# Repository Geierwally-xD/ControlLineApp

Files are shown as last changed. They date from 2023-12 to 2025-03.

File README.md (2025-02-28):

# ControlLineApp
Geierwally's stroke engine throttle control application for controlled line model planes
Display-picture
- Realizes full throttle control over control lines
- optional automatic flight position depended throttle control
- flight position sensor = MPU 6050 gyroscope accelerometer unit
- optional functions like retractable landing gear
Display-picture
- Hardware PCB design included, done with KiCad 8.0
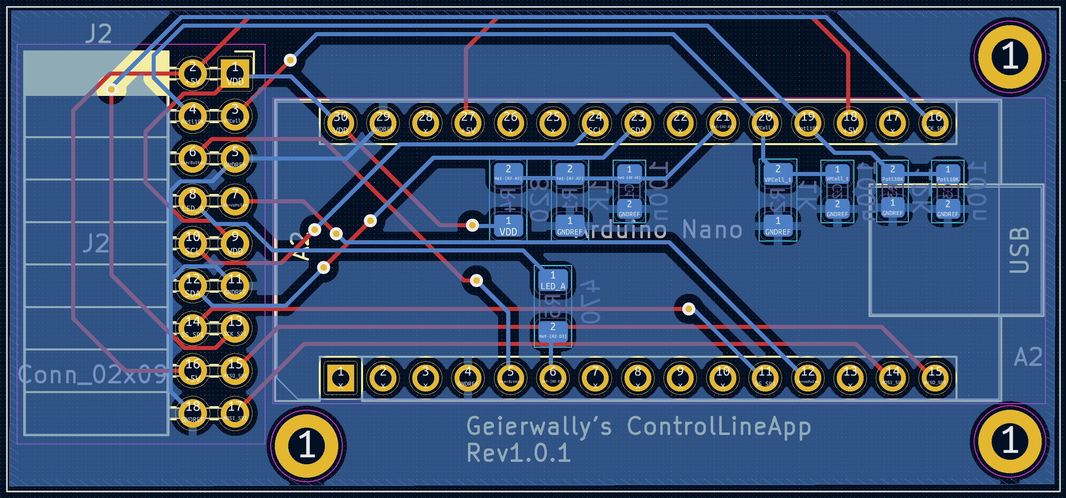
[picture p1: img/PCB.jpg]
Display-picture

- Full Software project included, done for Arduino Nano with VS Code and PlatformIO (optional Arduino IDE)
- See short video clip of position control and landing gear with landing light:
https://www.youtube.com/watch?v=91i4-DDLWDE

Geierwally's Verbrennungsmotor- Drosselvergasersteuerung für Fesselflugmodelle
Display-picture
- Drosselvergaser - Steuerung über Steuerdrähte mit optional automatischer Regelung über Fluglageerkennung
- Fluglagenerkennung über MPU 6050 Gyroskop Accelerometer - Einheit
- Optionale Funktionen wie Einziehfahrwerk
Display-picture
- Komplettes Hardware Platinenlayout enthalten, mit KiCad 8.0 entflochten
Display-picture
- Komplettes Software Projekt enthalten, für  Arduino Nano, entwickelt mit VS Code und PlatformIO (optional Arduino IDE)
- Kurzer Videoclip zeigt Regelung über Fluglage sowie Einziehfahrwerk und Landescheinwerfer:
https://www.youtube.com/watch?v=91i4-DDLWDE

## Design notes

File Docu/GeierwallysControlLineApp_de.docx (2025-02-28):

# Geierwally‘s Control – Line – Application

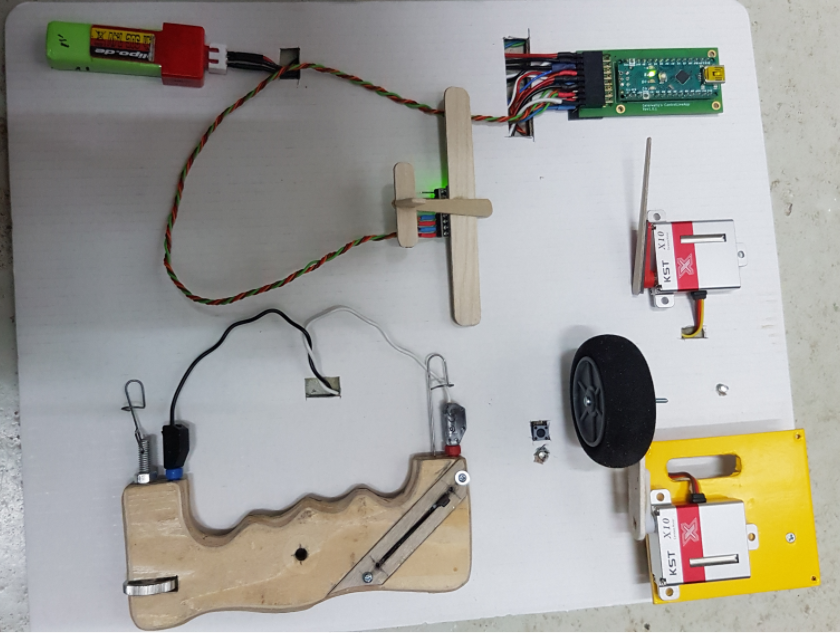
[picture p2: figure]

Geierwally‘s Control – Line – Application (GCLA) realisiert eine Drosselsteuerung in Verbindung mit einer Lagekontrolle und Zusatzfunktionen für Fesselflugmodelle mit Verbrennungsmotor.

Diese ermöglicht den Start des Modells ohne Helfer, einen jederzeit unterbrechbaren Flug sowie eine optionale fluglagenabhängige automatische Steuerung des Drosselvergasers.

Das Geberpoti für die Gassteuerung befindet sich im Steuergriff. Das Gebersignal wird durch die beiden Steuerlitzen übertragen, von einem Mikrocontroller (Arduino Nano) ausgewertet und über ein Servo mechanisch an den Drosselvergaser des Antriebsmotors weitergeleitet. Eine LED im Randbogen des Modells signalisiert den Betriebszustand des Controllers, sowie während des Fluges die verbleibende Flugzeit. Optional kann während des Fluges die lageabhängige Drosselsteuerung aktiviert bzw. deaktiviert werden. Die Lagesteuerung stellt den Motor automatisch im Steigflug mager bzw. im Sinkflug fetter. Die Regelbereiche sind teachbar. Optional kann Expo von 10 – 100% auf die Regelung gemappt werden. Ebenso sind minimale Drosselposition sowie die Position für Motorabsteller teachbar. Flugzeiten sind von 1 – 10 Minuten einstellbar. Nach jeder Minute wird die verbleibende Flugzeit über die Status-LED blinkend angezeigt. Ist die Flugzeit abgelaufen, wird dies durch Dauerblinken der LED sowie durch kurzes Drosseln des Motors für eine Sekunde signalisiert.

Zusätzlich werden vom Mikrocontroller noch beide Zellspannungen des Versorgungsakkus (2S LiPo 330 mAh) überwacht. Sinkt diese bei einer oder beiden Zellen unter 3,5 V, wird dies ebenso durch Dauerblinken der Status – LED signalisiert. Über kurze Drosselimpulse können die Fluglageregelung ein- bzw. ausgeschaltet sowie Zusatzfunktionen wie Einziehfahrwerk oder Landescheinwerfer gesteuert werden.

## 1. Beschreibung der Hardwarekomponenten

Kern der Steuerung ist ein Arduino Nano Mikrocontroller. Sensor für die Fluglageregelung ist eine MPU 6050 Gyroskop- Accelerometer – Einheit. Einlesen der Sensorsignale erfolgt über I²C Schnittstelle. Weitere Anschlussbelegungen sind anhand des Schaltplanes und Layouts im KiCad Projekt ersichtlich. Als Geber für die Gassteuerung dient ein lineares Potentiometer, welches im Steuergriff des Fesselflugmodells verbaut ist.

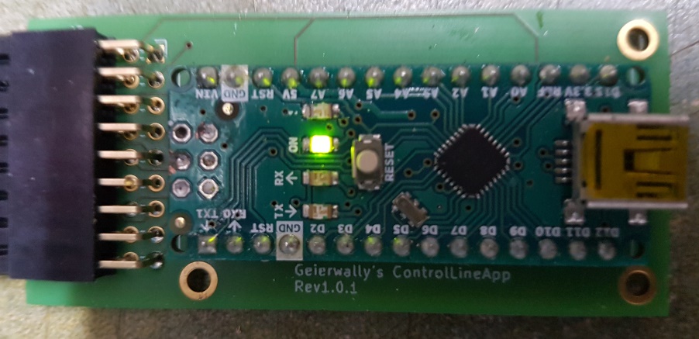
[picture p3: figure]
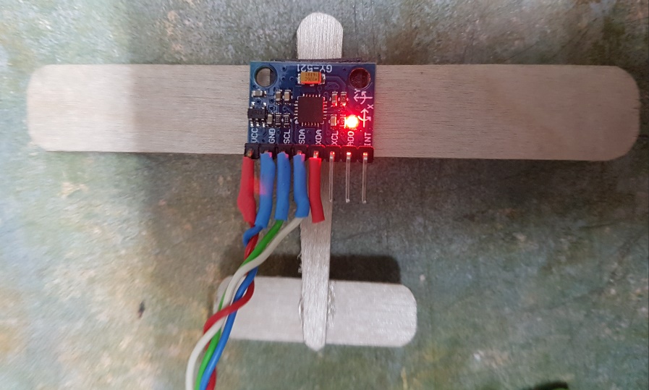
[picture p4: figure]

## 2. Einbau der Steuerkomponenten ins Modell

Controllerplatine, Versorgungsakku sowie das Servo können je nach Platz in Tragfläche oder Rumpf eingebaut werden. Hierbei sollte der Akkuschacht leicht zugänglich sein. Die MPU 6050 Gyroskop – Einheit sollte am Drehpunkt der Quer und Längsachse eingebaut werden. Hierbei kann man die MPU 6050 Sensoreinheit optional normal oder invertiert nach unten hängend montieren. Die Sensoreinheit unbedingt schwingungsgedämpft am besten mittels Klebepads für Helikreisel montieren!

Das Gebersignal vom Steuergriff wird über Mikro- Bananenbuchsen in den inneren Randbogen der Tragfläche verbunden. Zur Vermeidung des Kurzschlusses der Geberleitung ist das Steuerdreieck des Fesselflugmodells aus nichtleitendem Material wie z.B. Pertinax anzufertigen.

## 3. Stromlaufplan

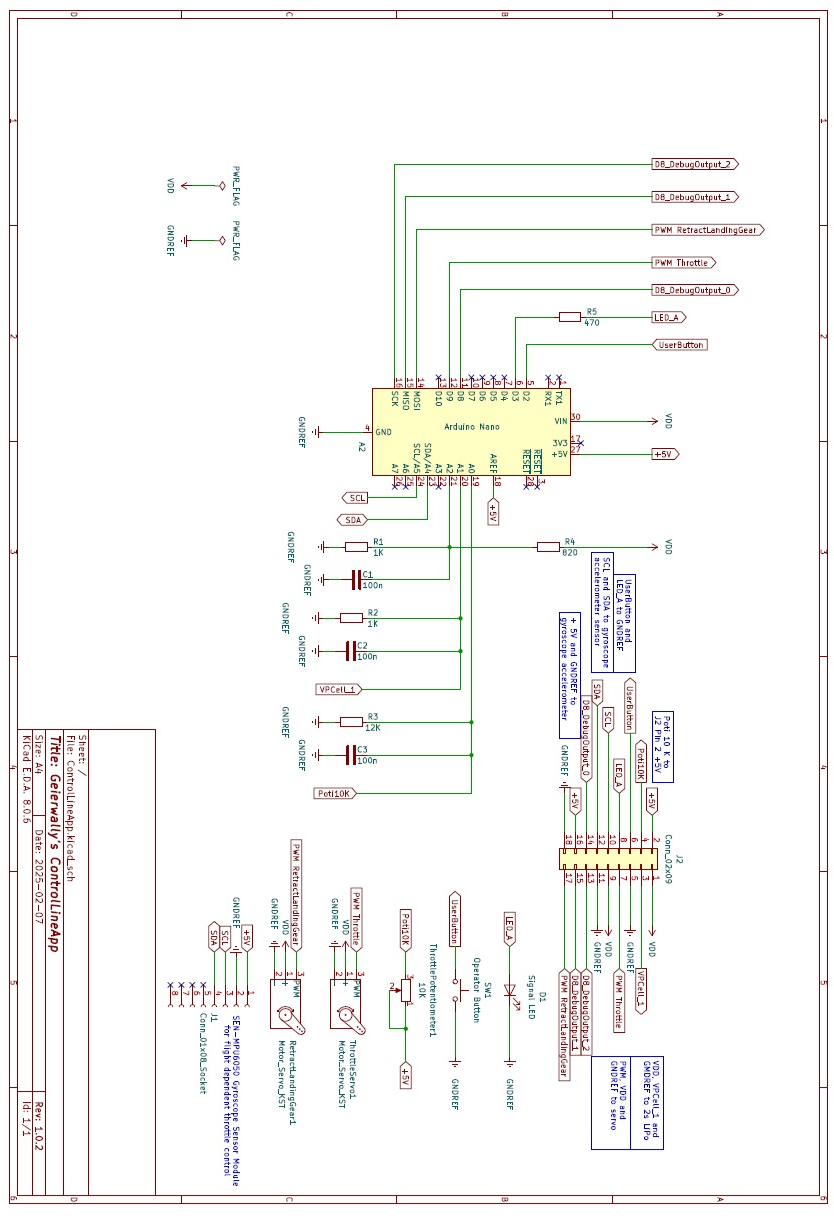
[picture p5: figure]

## 4. Anlernen von Servopositionen , Flugzeittimer und Spannungsüberwachung

Zur Vermeidung mechanischer Blockaden sind vorm ersten Teach der Servopositionen die Steuergestänge vom Servo zum Drosselvergaser sowie wenn verwendet zum Einziehfahrwerk zu lösen.

Die vordere Endlage des Servos (Vollgas) ist mechanisch blockadefrei einzustellen. Gleiches gilt für Einziehfahrwerk eingefahren.

Um ins Teachmenü zu kommen, ist der Anwenderbutton gedrückt zu halten, bis die Status LED das entsprechende Menü durch Blinken signalisiert. Folgende Hauptteachmenüpunkte sind implementiert:

Teach Servo Drosselposition 2 * blinken

Teach Servo Endlage (Motor Absteller) 3 * blinken

Teach Servo revers 4 * blinken

Geberpoti Endlagen 5 * blinken

Einziehfahrwerk 6* blinken

Spannungsüberwachung 7 * blinken

Gyroskop – Teachmenü 8 * blinken

Flugzeit – Timer 9 * blinken

Der Positionsteach wird in den folgenden Schritten beschrieben und sollte genau in dieser Reihenfolge durchgeführt werden.

### 4.1. Anlernen der Geberendlagen (Hauptmenü 5 * blinken)

Hierzu den Menübutton so lange gedrückt halten, bis die Status LED in Folge fünf Mal geblinkt hat.

Im Untermenü blinkt die LED einmal bzw. zweimal je Endlage. Das Poti zunächst in eine Endlage stellen und den Teachbutton kurz betätigen. LED blinkt jetzt zweimal, damit das Poti in die zweite Endlage bringen und mit kurzem Button-Klick bestätigen. Die Positionen sind jetzt permanent im E²Prom des Mikrocontrollers gespeichert.

### 4.2. Servo Stellrichtungsumkehr, nur wenn erforderlich (Hauptmenü 4 * blinken)

Hierzu den Menübutton solange gedrückt halten, bis die Status LED in Folge vier Mal geblinkt hat. Dieser Menüpunkt ist nur zu wählen, wenn das Servo je nach Einbaulage im Modell Stellrichtungsumkehr benötigt. In diesem Menüpunkt ist keine Bestätigung mittels Teachbutton erforderlich. Das Servo aktiviert bzw. deaktiviert die Stellrichtungsumkehr. Auch diese Position ist damit permanent im E²Prom des Mikrocontrollers gespeichert.

### 3.3 Servo Endlage Motorabsteller (Hauptmenü 3 * blinken)

Geber in Mittelposition bringen und den Menübutton solange gedrückt halten, bis die Status LED in Folge drei Mal geblinkt hat. Geber in Position stellen, dass Drosselvergaser in Endlage für Motorabsteller steht, ohne zu blockieren. Die Position mit kurzer Betätigung des Menübuttons bestätigen. Die Position bleibt im E²Prom des Mikrocontrollers gespeichert.

### 3.4 Servo Minimale Drosselposition (Hauptmenü 2 * blinken)

Geber in Mittelposition bringen und den Menübutton solange gedrückt halten, bis die Status LED in Folge zwei Mal geblinkt hat. Geber in Position stellen, dass Drosselvergaser in minimaler Drosselposition steht. Diese Position sollte zuvor mit laufendem Motor getestet und am Geberstick markiert werden. Gleiches gilt für alle weiteren Drosselvergaserpositionen. Position mit kurzer Betätigung des Menübuttons bestätigen. Die Position bleibt im E²Prom des Mikrocontrollers gespeichert.

### 3.5 Versorgungsspannung Einzelzellüberwachung (Hauptmenü 7 * blinken)

Mit dieser Funktion werden die beiden Analog- / Digitalwandler Eingänge der Spannungsüberwachung kalibriert. Dazu den Versorgungsakku komplett aufladen, bis Einzelzellspannung von 4,2 Volt erreicht ist. Den Akku anstecken, Menübutton solange gedrückt halten, bis die Status-LED sieben Mal in Folge blinkt. Eine weitere Bestätigung ist in dieser Teachfunktion nicht notwendig. Der Kalibrierwert wird im E²Prom des Mikrocontrollers permanent gespeichert. Fällt nun eine oder beide LiPo- Zellen unter 3,5 Volt, signalisiert die Status- LED den Fehler mit Dauerblinken.

### 3.6 Einstellung Flugzeittimer (Hauptmenü 9 * blinken)

Mit dieser Funktion wird der Flugzeittimer eingestellt. Zeiten von 1 Minute – 10 Minuten sind je nach Tankgröße und daraus resultierender Motorlaufzeit möglich. Ist der Timer aktiv, werden während des Fluges jede Minute durch Blinken der Status-LED die verbleibende Flugzeit in Minuten signalisiert. Ist Ende der Flugzeit erreicht, geht die Status-LED ins Dauerblinken über und der Motor drosselt kurz für eine Sekunde. Ende Flugzeit sollte natürlich signalisieren, bevor der Tank leer ist, damit man mit der Drosselfunktion noch sicher landen kann.

Zum Teach den Menübutton solange gedrückt halten, bis die Status-LED in Folge neun Mal blinkt.

Man befindet sich nun im Submenü und die LED blinkt ein bis zehn Mal je Anzahl der Flugminuten. Man muss hier bei der gewünschten Minutenzahl mit dem Menübutton kurz bestätigen. Auch diese Daten bleiben permanent gespeichert. Der Flugzeittimer wird durch kurzes Betätigen des Menübuttons gestartet und ebenso wieder gestoppt. Flugzeitende bestätigt man auch durch kurzes Betätigen des Menübuttons. Ist der Timer gestartet, signalisiert er sofort mit LED blinken die eingestellte Flugzeit.

## 5. Fluglageabhängige Drosselsteuerung über Gyroskop Accelerometer (Hauptmenü 8 * blinken)

Die GCLA verfügt über eine optional aktivierbare fluglageabhängige Drosselsteuerung. Die Erfassung der Fluglage erfolgt über eine MPU 6050 Gyroskop – Accelerometer- Sensoreinheit. Zur Lageregelung werden die Drosselpositionen für Neutral und Rückenflug (70 – 80% Drehzahl) sowie die Drosselposition für Sturzflug (zwischen 5 – 20% Drehzahl) geteacht. Die Drehzahlpositionen sollten vorm Teach bei laufendem Motor mit Drehzahlmesser eingestellt und am Geber markiert werden. Das erleichtert den späteren Teach.

Die Fluglageregelung kann während des Fluges jederzeit mit kurzem Drosseln des Motors ein – bzw. ausgeschaltet werden. Dies wird über die Status LED signalisiert. Zwei Mal kurz blinken = Lageregelung ein. Das optionale Deaktivieren ermöglicht einen Start des Modells ohne Lageregelung und mit Vollgas. Sonst wären ja in Neutrallage nur die angelernten 70 – 80% Drehzahl aktiv. Fürs Starten sollte es schon Vollgas sein. In Folge die Beschreibung des Lageregelungs- Teach- Submenüs

Um ins Lageregelungs Teach- Submenü zu kommen, den Menübutton solange gedrückt halten, bis die Status-LED acht Mal in Folge blinkt. Man befindet sich nun im Submenü der Lageregelung.

Folgende Submenüpunkte sind implementiert:

Sensoreinheit normale Einbaulage 1 * blinken

Sensoreinheit hängende Einbaulage 2 * blinken

Sensoreinheit kalibrieren 3 * blinken

Drosselposition Normalflug 4 * blinken

Drosselposition Sturzflug 5 * blinken

Expo 6 * blinken

Lageregelung ein / aus 7 * blinken

Servo Empfindlichkeit 8 * blinken

Lageregelung Teachmenü verlassen 9 * blinken

### 4.1 Normale Einbaulage Gyroskop- Accelerometereinheit (Submenü 1 * blinken)

Diese Option wählen, wenn die Gyroskop- Accelerometer – Sensoreinheit normal von oben montiert ist. Je nach Platz im Modell, kann diese von oben normal oder von unten hängend montiert werden. Die Sensoreinheit sollte am Drehpunkt der Quer und Längsachse schwingungsgedämpft montiert werden. Hierzu können Klebepads von Helikreiseln verwendet werden. Für diese Funktion nach einmaligem LED blinken mit dem Menübutton kurz bestätigen. Die Option wird gespeichert und man befindet sich sofort wieder im Gyro - Teach – Submenü.

### 4.2 Hängende Einbaulage Gyroskop- Accelerometereinheit (Submenü 2 * blinken)

Diese Option wählen, wenn die Gyroskop- Accelerometer – Sensoreinheit hängend montiert wurde. Funktion ist sonst analog zu Menüpunkt 4.1. Den Teach nach zweimaligem blinken der Status – LED mit dem Menübutton bestätigen.

### 4.3 Kalibrierung der Gyroskop- Accelerometereinheit (Submenü 3 * blinken)

Mit diesem Menüpunkt wird die Gyroskop- Accelerometereinheit kalibriert. Dazu nach dreimaligem LED- Blinken mittels Menübuttonklick bestätigen. Die Kalibrierung dauert eine Minute. In dieser Zeit sollte das Modell in allen Achsen gedreht werden, dass der Sensor in alle möglichen Fluglagen kommt. Nach einer Minute werden die ermittelten Kalibrierdaten permanent gespeichert und man ist automatisch wieder im Gyro – Teach - Submenü.

### 4.4 Lagekontrolle Normalflug - Drosselposition (Submenü 4 * blinken)

Hiermit wird die Drosselposition für Normalflug / Rückenflug geteacht. Diese sollte zwischen 70 und 80% Drehzahl liegen. Am besten vorher mit Drehzahlmesser ermitteln und am Geber markieren. Zum Teach der Position im Submenü nach viermaligem LED blinken mit Menübutton bestätigen, den Geber in die gewünschte Position bringen und mit nochmaliger kurzer Betätigung des Teachbuttons speichern. Danach ist man wieder im Gyro – Teach - Submenü.

### 4.5 Lagekontrolle Sturzflug - Drosselposition (Submenü 5 * blinken)

Hiermit wird die Drosselposition für Sturzflug geteacht. Diese sollte zwischen 5 und 15% Drehzahl liegen. Am besten vorher mit Drehzahlmesser ermitteln und am Geber markieren. Zum Teach der Position im Submenü nach fünfmaligem LED blinken mit Menübutton bestätigen, den Geber in die gewünschte Position bringen und mit nochmaliger kurzer Betätigung des Teachbuttons speichern. Danach ist man wieder im Gyro – Teach - Submenü.

### 4.6 Expo Lagekontrolle (Submenü 6 * blinken)

Mit dieser Funktion kann man die fluglagenabhängige Drosselsteuerung mit Expo überlagern. Dies funktioniert auf ähnliche Weise wie man Expo bei den RC Modellen verwendet. Zur Funktionswahl im Submenü nach sechsmaligem LED blinken mit Menübutton bestätigen.

Man kann nun zwischen 0% = lineare Regelkurve und 100% = maximale exponentielle Überlagerung in Zehnerschritten wählen. Folgende Regelkurven wurde direkt mit der Steuerung aufgezeichnet und verdeutlichen die Anwendung von Expo auf die Drosselsteuerung:

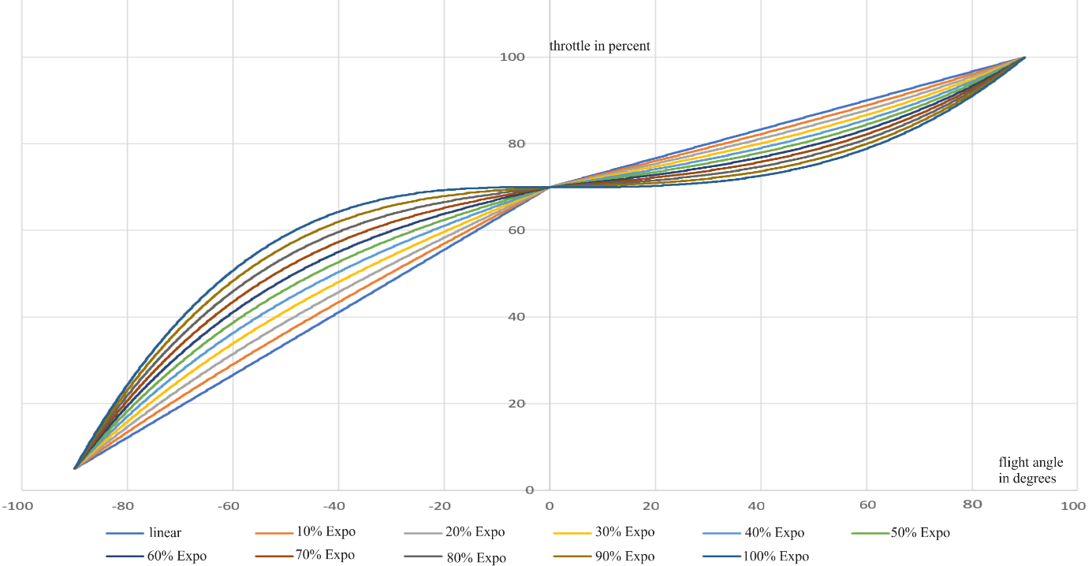
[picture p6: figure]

X- Achse zeigt Flugwinkel von -90° = senkrechter Sturzflug, 0° = Neutralfluglage, 90° = senkrechter Steigflug

Y- Achse zeigt Drosselstellung (0 - 100 Prozent von maximaler Drehzahl)

Zum Expo - Teach im Submenü nach sechsmaligem LED blinken mit Menübutton bestätigen.

Im Expo – Teach – Menü blinkt die Status – LED von ein bis zehnmal kurz zur Wahl der Expo in Prozent. Einmal blinken = 10% Expo, zweimal blinken = 20% Expo…..zehnmal blinken = 100% Expo. Nach dem Blinken der gewünschten prozentualen Expo mit Menübutton kurz bestätigen. Für lineare Kurve, also keine Expo blinkt die Status LED nach der maximalen Expo - Position einmal lang.

Ob und wieviel Expo benötigt wird, muss man erfliegen. Auch diese Daten bleiben permanent gespeichert.

### 4.7 Fluglageregelung ein / aus (Submenü 7 * blinken)

Diese Option aktiviert (1 * blinken) bzw. deaktiviert (2 * blinken) die Fluglageregelung. Die Lageregelung kann bei aktiviertem Betrieb dann wahlweise mit kurzem Drosseln des Motors während des Fluges ein bzw. ausschalten. Regeln tut es erst, wenn der Drosselgeber auf dem eingestellten Wert für Neutralflug bzw. darüber in Richtung Vollgas steht. Man kann also auch bei aktiver Fluglageregelung jederzeit den Motor drosseln und den Flug beenden. Die Wirkung der Fluglageregelung wird in folgendem kurzen Videoclip mit maximaler also 100% überlagerter Expo gezeigt. Video GCLA Lageregelung (https://www.youtube.com/shorts/paRSoQgenMU)

Zur Funktionswahl im Submenü nach ein- bzw. zweimaligem LED blinken mittels Menübutton bestätigen. Damit wird die Option permanent gespeichert und man ist wieder im Gyro – Teach – Submenü.

### 4.8 Fluglageregelung Servoempfindlichkeit (Submenü 8 * blinken)

Diese Option startet den Teach der Servoempfindlichkeit. Zwischen einmaligem (schnell) bis fünfmaligem (langsam) LED blinken kann man wählen, wie schnell das Servo auf die Lageregelung reagiert. Bei sechsmaligem LED blinken ist die Verzögerung deaktiviert und das Servo reagiert direkt mit maximaler Stellgeschwindigkeit auf die Lageregelung. Mittels Bestätigung durch Menübutton wird die Option permanent gespeichert und man ist wieder im Gyro-Teach-Submenü.

### 4.9 Fluglageregelung Teach Submenü beenden (Submenü 9 * blinken)

Mit dieser Option verlässt man das Gyro – Teach – Submenü und ist wieder im normalen Steuermenü. Zur Funktionswahl im Submenü nach neunmaligem LED blinken mit Menübutton bestätigen.

## 6. Einziehfahrwerk und Zusatzfunktionen (Hauptmenü 6 * blinken)

In der GCLA sind drei digitale Zusatzfunktionen sowie die Steuerung eines Einziehfahrwerks realisiert. Diese können im Flugbetrieb mittels kurzer Drosselimpulse geschaltet werden. Zwei kurze Drosselimpulse steuern das Einziehfahrwerk. Drei, vier und fünf kurze Drosselimpulse schalten die digitalen Zusatzfunktionen. Zusatzfunktion 1 kann optional mit dem Einziehfahrwerk verknüpft werden zur Steuerung eines Landescheinwerfers. In dieser Option schaltet die Funktion bei ausgefahrenem Fahrwerk automatisch ein und bei eingefahrenem Fahrwerk automatisch aus. Die folgenden Unterkapitel beschreiben das Teachmenü für die Funktion Einziehfahrwerk.

### 5.1 Servoendlage Einziehfahrwerk ausgefahren (Submenü 1 * blinken)

Mit diesem Menüpunkt wird die Servoendlage des Einziehfahrwerks im ausgefahrenen Zustand angelernt. Die Position wird mit dem Drosselgeber Poti gestellt. Durch Bestätigung mittels Menübutton wird die Position permanent gespeichert. Die Position für eingefahrenes Fahrwerk ist bei maximalem Ausschlag des Servos mechanisch einzustellen.

### 5.2 Einziehfahrwerk Servo Revers (Submenü 2 * blinken)

Diese Option invertiert die Stellrichtung des Einziehfahrwerkservos. Einmaliges LED blinken = normal, zweimaliges LED blinken = invertierte Stellrichtung. Mittels Menübutton wird die Option permanent gespeichert und das Teachmenü des Einziehfahrwerksservos ist aktiv.

### 5.3 Einziehfahrwerk Servo Stellgeschwindigkeit (Submenü 3 * blinken)

Mit diesem Submenü wird die Stellgeschwindigkeit des Einziehfahrwerksservos verändert. Es stehen Optionen von einfach blinken (schnell) bis fünffach blinken (langsam) zur Verfügung. Mit sechsfach blinken wird die maximale Stellgeschwindigkeit aktiviert. Auch hier wird die gewählte Option nach blinken mittels Menübutton permanent gespeichert und ins Teachmenü des Einziehfahrwerksservos zurückgeschaltet.

### 5.4 Verknüpfung Zusatzfunktion Landescheinwerfer (Submenü 4 * blinken)

Dieses Submenü verknüpft optional die digitale Zusatzfunktion 1 mit dem Einziehfahrwerk. Dies kann beispielsweise zum Schalten eines Landescheinwerfers verwendet werden. Folgende Optionen stehen zur Verfügung: einfach blinken = Zusatzfunktion 1 verknüpft (Fahrwerk ausgefahren und Landescheinwerfer ein), zweifach blinken = Zusatzfunktion 1 invertiert verknüpft (Fahrwerk ausgefahren und Landescheinwerfer aus), dreifach blinken = keine Verknüpfung von Zusatzfunktion 1 Mit dem Menübutton wird die Option permanent gespeichert und zurück ins Teachmenü des Einziehfahrwerksservos geschaltet. Auch wenn die Verknüpfung aktiv ist kann die Zusatzfunktion 1 parallel mit drei Drosselimpulsen geschaltet werden.

### 5.5 Teachmenü Einziehfahrwerk beenden (Submenü 5 * blinken)

Mit Bestätigung dieser Option über Menübutton wird das Teachmenü des Einziehfahrwerksservos beendet.

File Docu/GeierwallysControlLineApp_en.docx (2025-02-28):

# Geierwally's Control – Line – Application


Geierwally's Control – Line – Application (GCLA) realizes a throttle control in combination with position control and additional functions for control line models with stroke engines.

This allows the model to be started without helpers, a flight that can be interrupted at any time and an optional automatic control of the throttle carburettor depending on the flight position.

The linear potentiometer for the throttle control is located in the control handle. The encoder signal is transmitted through the two control lines, evaluated by a microcontroller (Arduino Nano) and mechanically transmitted via a servo to the throttle carburettor of the stroke engine. An LED in the edge arc of the model indicates the operating status of the controller, as well as the remaining flight time during the flight. Optionally, the position-dependent throttle control can be activated or deactivated during the flight. The position control automatically makes the engine leaner during ascending - and fatter during descending flight. The control areas can be taught. Optionally, expo from 10 – 100% can be mapped to the control. The minimum throttle position as well as the position for engine shut-off can be also taught. Flight times can be set from 1 – 10 minutes. After each minute, the remaining flight time is flashed by the status LED. If the flight time has elapsed, this is signalled by continuous flashing of the LED and by briefly throttling the engine for one second.

In addition, the microcontroller monitors both cell voltages of the supply battery (2S LiPo 330 mAh). If this drops below 3.5 V for one or both cells, this is also signalled by continuous flashing of the status LED. Short throttle pulses can be used to switch the flight attitude control on or off and to control additional functions such as retractable landing gear or landing lights.

## 1. Description of Hardware Components

The core of the control system is an Arduino Nano microcontroller. The position control sensor is an MPU 6050 gyroscope accelerometer unit. The sensor signals are read in via I²C interface. Further connection assignments can be seen in the circuit diagram and layout in the KiCad project. The encoder for the throttle control is a linear potentiometer, which is installed in the control handle of the control line model.


## 2. Installation of the control components in the model

The controller board, power supply battery and servo can be installed in the wing or fuselage, depending on the space. The battery bay should be easily accessible. The MPU 6050 gyroscope unit should be installed at the pivot point of the transverse and longitudinal axis. The MPU 6050 sensor unit can optionally be mounted normally or inverted and suspended downwards. Be sure to mount the sensor unit vibration-damped, preferably using adhesive pads for helicopter gyroscopes!

The encoder signal from the control handle is connected to the inner edge arch of the wing via micro banana bushings. To avoid a short circuit of the encoder cable, the control triangle of control line model must be made of non-conductive material such as Pertinax.

## 3. Schematic


## 4. Teach-in servo positions, time-of-flight timer and voltage monitoring

To avoid mechanical blockages, the control linkages from the servo to the throttle carburetor and, if used, to the retractable landing gear must be disconnected before the servo positions are taught for the first time. The front end position of the servo (full throttle) can be adjusted mechanically without blockage. The same applies to retractable landing gear retracted. To access the teach menu, press and hold the user button until the status LED signals the corresponding menu by flashing. The following main teach menu items are implemented:

teach servo throttle position 2 * flashing

teach servo end position (motor shut-off) 3 * flashing

teach servo direction 4 * flashing

encoder potentiometer end positions 5 * flashing

retractable landing gear 6 * flashing

voltage monitoring 7 * flashing

gyroscope – teach menu 8 * flashing

flight time – timer 9 * flashing

Position teaching is described in the following steps and should be done exactly in this order.

### 4.1. Teach-in of the encoder end positions (main menu 5 * flashing)

To do this, hold down the menu button until the status LED has flashed five times in a row.

In the submenu, the LED flashes once or twice for each end position. First, place the potentiometer in an end position and press the teach button briefly. LED now flashes twice to bring the potentiometer to the second end position and confirm with a short button click. The positions are now permanently stored in the E²Prom of the microcontroller.

### 4.2. Servo direction reversal, only when required (main menu 4 * flashing)

To do this, press and hold the menu button until the status LED has flashed four times in a row. This menu item can only be selected if the servo needs to be reversed depending on the mounting position in the model. In this menu item, no confirmation via the teach button is required. The servo activates or deactivates the reversal of the direction of travel. This position is also permanently stored in the E²Prom of the microcontroller.

### 3.3 Servo end position motor shut-off (main menu 3 * flashing)

Move the sensor to the middle position and hold down the menu button until the status LED has flashed three times in succession. Position the encoder potentiometer so that the throttle carburettor is in the end position for the engine shut-off without blocking. Confirm the position by briefly pressing the menu button. The position remains stored in the E²Prom of the microcontroller.

### 3.4 Servo Minimum throttle position (main menu 2 * flashing)

Move the encoder potentiometer to the middle position and hold down the menu button until the status LED has flashed twice in succession. Position the potentiometer so that the throttle carburettor is in the minimum throttle position. This position should be tested beforehand with the engine running and marked on the transducer stick. The same applies to all other throttle carburettor positions. Confirm the position by briefly pressing the menu button. The position remains stored in the E²Prom of the microcontroller.

### 3.5 Supply Voltage Single Cell Monitoring (Main Menu 7 * Flashing)

This function is used to calibrate the two analogue to digital converters inputs of the voltage monitor. To do this, fully charge the supply battery until a single-cell voltage of 4.2 volts is reached. Plug in the battery, press and hold the menu button until the status LED flashes seven times in a row. Further confirmation is not necessary in this teaching function. The calibration value is permanently stored in the E²Prom of the microcontroller. If one or both LiPo cells fall below 3.5 volts, the status LED signals the fault with continuous flashing.

### 3.6 Setting flight time timer (main menu 9 * flashing)

This function is used to set the flight time timer. Times of 1 minute – 10 minutes are possible depending on the tank volume and the resulting engine runtime. If the timer is active, the remaining flight time in minutes is signalled every minute during the flight by flashing the status LED. When the end of the flight time is reached, the status LED switches to continuous flashing and the engine throttles briefly for a second. End of flight time should of course signal before the tank is empty, so that you can still land safely with the throttle function.

To teach, press and hold the menu button until the status LED flashes nine times in a row.

You are now in the submenu and the LED flashes one to ten times depending on the number of flight minutes. You have to confirm the desired number of minutes with the menu button. This data is also stored permanently. The time-of-flight timer is started and stopped again by briefly pressing the menu button. The end of the flight time can also be confirmed by briefly pressing the menu button. When the timer is started, it immediately signals the set flight time with LED flashing.

## 5. Position-dependent throttle control via gyroscope accelerometer (main menu 8 * flashing)

The GCLA has an optionally activated position-dependent throttle control. The flight position is recorded by an MPU 6050 gyroscope – accelerometer sensor unit. For position control, the throttle positions for neutral and inverted flight (70 – 80% rpm) as well as the throttle position for dive (between 5 – 20% rpm) are taught. The speed positions should be set with a tachometer before teaching while the engine is running and marked on the encoder. This makes it easier to teach it later.

The position control can be switched on or off at any time during the flight by briefly throttling the engine. This is indicated by the status LED. Blink briefly twice = position control active. The optional deactivation allows the model to be started without position control and at full throttle. Otherwise, only the learned 70 – 80% speed would be active in neutral position. It should be full throttle for the start. Below is the description of the position control teach submenu

To access the Position Control Teach submenu, press and hold the menu button until the status LED flashes eight times in a row. You are now in the submenu of the position control.

The following submenu items are implemented:

sensor unit normal mounting position 1 * flashing

sensor unit hanging mounting position 2 * flashing

calibrate sensor unit 3 * flashing

throttle position normal flight 4 * flashing

throttle position dive 5 * flashing

expo 6 * flashing

position control on / off 7 * flashing

servo sensitivity 8 * flashing

position control leave teach menu 9 * Flashing

### 4.1 Normal mounting position gyroscope accelerometer unit (submenu 1 * flashing)

Select this option if the gyroscope accelerometer sensor unit is normally mounted from above. Depending on the space in the model, it can be mounted normally from above or suspended from below. The sensor unit should be mounted at the pivot point of the transverse and longitudinal axis in a vibration-damped manner. For this purpose, adhesive pads of helicopter gyroscopes can be used. For this function, after a single LED flash, briefly confirm with the menu button. The option will be saved and you will immediately be back in the Gyro - Teach - submenu.

### 4.2 Hanging mounting position gyroscope accelerometer unit (submenu 2 * flashing)

Select this option if the gyroscope accelerometer sensor unit is suspended mounted. Function is otherwise analogous to menu item 4.1. Confirm the teach after blinking the status LED with the menu button.

### 4.3 Calibration of the gyroscope accelerometer unit (submenu 3 * flashing)

This menu item is used to calibrate the gyroscope accelerometer unit. To do this, confirm after flashing the LED three times by clicking on the menu button. Calibration takes one minute. During this time, the model should be rotated in all axes so that the sensor comes into all possible flight positions. After one minute, the calibration data is permanently stored and you are automatically back in the Gyro – Teach – submenu.

### 4.4 Position control normal flight - throttle position (submenu 4 * flashing)

This is used to teach the throttle position for normal flight / inverted flight. This should be between 70 and 80% speed. It is best to determine beforehand with a tachometer and mark it on the encoder. To teach the position in the submenu, after flashing four LEDs, confirm with the menu button, move the encoder to the desired position and save it by pressing the teach button again. After that, you are back in the Gyro – Teach – submenu.

### 4.5 Position control dive - throttle position (submenu 5 * flashing)

This is used to teach the throttle position for diving. This should be between 5 and 15% speed. It is best to determine beforehand with a tachometer and mark it on the encoder. To teach the position in the submenu, after flashing the LED five times, confirm with the menu button, move the encoder to the desired position and save it by pressing the teach button again. After that, you are back in the Gyro – Teach – submenu.

### 4.6 Expo position control (submenu 6 * flashing)

With this function, you can overlay the position-dependent throttle control with expo. This works in a similar way to how you use expo on the RC models.

Confirm with the menu button after status LED has flashed six times. You can now choose between 0% = linear control curve and 100% = maximum exponential superposition in steps of ten. The following control curves were recorded directly with the controller and illustrate the application of expo to throttle control:


X-axis shows flight angle of -90° = vertical descent flight, 0° = normal/invert flight, 90° = vertical ascend flight

Y-axis shows throttle position (0 - 100 percent of maximum speed)

In the Expo – Teach menu, the status LED flashes from one to ten times briefly for the selection of the expo in percentage. One flash = 10% Expo, two flashes = 20% Expo.....ten flashes = 100% Expo. After flashing the desired percentage expo, confirm briefly with the menu button. For linear curve, i.e. no expo, the status LED flashes once long after the maximum expo position.

Whether and how much expo is needed has to be flown. This data is also stored permanently.

### 4.7 Flight control on / off (submenu 7 * flashing)

This option activates (1 * flashing) or deactivates (2 * flashing) position control. The position control in active state can be switched on or off by briefly throttling the engine during the flight. It only regulates when the throttle encoder potentiometer is at the set value for neutral flight or above in the direction of full throttle. This means that you can throttle the engine and end the flight at any time, even with active position control. The effect of the position control is shown in the following short video clip with a maximum expo, i.e. 100% superimposed. Video GCLA Position Control (https://www.youtube.com/shorts/paRSoQgenMU)

To select function in the submenu, confirm with menu button if LED has flashed one or two times. This will save the option permanently and you are back in the Gyro – Teach – submenu.

### 4.8 Flight control servo sensitivity (submenu 8 * flashing)

This option starts teaching the servo sensitivity. Between single (fast) to five (slow) LED flashes, you can choose how quickly the servo reacts to the position control. If the LED flashes six times, the delay is deactivated and the servo reacts directly to the position control at maximum speed. By confirming with the menu button, the option is permanently saved and you are back in the gyro teach submenu.

### 4.9 Flight control leave teach submenu (Submenu 9 * Flashing)

With this option you leave the Gyro – Teach – submenu and are back in the normal control menu. To select function in the submenu, confirm with menu button if LED has flashed nine times.

## 6. Retractable landing gear and additional functions (main menu 6 * flashing)

The GCLA has three additional digital functions as well as the control of a retractable landing gear. These can be switched during flight operation by means of short throttle pulses. Two short throttle pulses control the retractable landing gear. Three, four and five short throttle pulses switch the additional digital functions. Additional function 1 can optionally be linked to the retractable landing gear to control a landing light. In this option, the function switches on automatically when the landing gear is extended and automatically switches off when the landing gear is retracted. The following subchapters describe the teach menu for the retractable landing gear function.

### 5.1 Servo end position retractable landing gear extended (submenu 1 * flashing)

This menu item is used to teach the servo end position of the retractable landing gear when extended. The position is set with the throttle sensor potentiometer. By confirming with the menu button, the position is permanently stored. The position for retracted landing gear must be adjusted mechanically at maximum deflection of the servo.

### 5.2 Retractable landing gear servo revers (submenu 2 * flashing)

This option inverts the direction of control of the retractable landing gear servo. Single LED flashing = normal, flashing LED twice = inverted direction. Pressing menu button saves the option permanently and the teach menu of the retractable landing gear is active.

### 5.3 Retractable landing gear servo speed (submenu 3 * flashing)

This submenu changes the actuation speed of the retractable landing gear servo. Options are available from single flash (fast) to five flashes (slow). The maximum positioning speed is activated with six flashes. Here, too, the selected option is permanently saved by pressing the menu button and switched back to the teach menu of the retractable landing gear.

### 5.4 Link additional function landing lights (submenu 4 * flashing)

This submenu optionally links the digital additional function 1 with the retractable landing gear. This can be used, for example, to switch a landing light. The following options are available: single flashing = additional function 1 linked (landing gear extended and landing lights on), double flashing = additional function 1 inverted linked (landing gear extended and landing lights off), triple flashing = no linking of additional function 1 With the menu button, the option is permanently saved and switched back to the teach menu of the retractable landing gear. Even if the link is active, the additional function 1 can be switched in parallel with three throttle pulses.

### 5.5 Leave teachmenu retractable landing gear (submenu 5 * flashing)

With confirmation of this option via the menu button, the teach menu of the retractable landing gear servo is closed.

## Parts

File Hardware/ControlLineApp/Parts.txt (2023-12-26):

Widerstand 1K 1206
https://www.conrad.de/de/p/tru-components-1584217-tc-hp06w2f1001t5e203-dickschicht-widerstand-1-k-smd-1206-0-5-w-1-100-ppm-c-1-st-tape-cut-1584217.html

Widerstand 470 Ohm 1206
https://www.conrad.de/de/p/tru-components-1585631-tc-hp06w2f4700t5e203-dickschicht-widerstand-470-smd-1206-0-5-w-1-100-ppm-c-1-st-tape-cut-1585631.html

Widerstand 820 Ohm 1206
https://www.conrad.de/de/p/tru-components-tc-1206s4j0821t5e203-dickschicht-widerstand-820-smd-1206-0-25-w-5-100-ppm-c-1-st-tape-cut-1585946.html

Widerstand 12K 0805
https://www.conrad.de/de/p/vishay-dcu-0805-1-12k-dcu-0805-dickschicht-widerstand-12-k-smd-0805-0-125-w-1-100-ppm-1-st-tape-cut-428140.html

Kondensator 100 n 0805
https://www.conrad.de/de/p/samsung-smd-keramik-vielschicht-kondensator-bauform-0805-x7r-100-nf-10-50-v-2752828.html

Buchsenleiste
https://www.conrad.de/de/p/econ-connect-buchsenleiste-standard-anzahl-reihen-2-polzahl-je-reihe-9-blw2x9-1-st-1492395.html

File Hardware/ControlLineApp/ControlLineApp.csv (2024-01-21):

ID | Bezeichner | Footprint | Stückzahl | Bezeichnung | Anbieter und Referenz
1 | A2 | Arduino_Nano | 1 | Arduino Nano
2 | J2 | PinSocket_2x09_P2.54mm_Horizontal | 1 | Conn_02x09 | https://www.conrad.de/de/p/econ-connect-buchsenleiste-standard-anzahl-reihen-2-polzahl-je-reihe-9-blw2x9-1-st-1492395.html
3 | R4 | R_1206_3216Metric_Pad1.30x1.75mm_HandSolder | 1 | 820 | https://www.conrad.de/de/p/tru-components-tc-1206s4j0821t5e203-dickschicht-widerstand-820-smd-1206-0-25-w-5-100-ppm-c-1-st-tape-cut-1585946.html
4 | R3 | R_0805_2012Metric_Pad1.20x1.40mm_HandSolder | 1 | 12K | https://www.conrad.de/de/p/vishay-dcu-0805-1-12k-dcu-0805-dickschicht-widerstand-12-k-smd-0805-0-125-w-1-100-ppm-1-st-tape-cut-428140.html
5 | C1,C3,C2 | C_0805_2012Metric_Pad1.18x1.45mm_HandSolder | 3 | 100n | https://www.conrad.de/de/p/samsung-smd-keramik-vielschicht-kondensator-bauform-0805-x7r-100-nf-10-50-v-2752828.html
6 | R2,R1 | R_1206_3216Metric_Pad1.30x1.75mm_HandSolder | 2 | 1K | https://www.conrad.de/de/p/tru-components-1584217-tc-hp06w2f1001t5e203-dickschicht-widerstand-1-k-smd-1206-0-5-w-1-100-ppm-c-1-st-tape-cut-1584217.html
7 | R5 | R_1206_3216Metric_Pad1.30x1.75mm_HandSolder | 1 | 470 | https://www.conrad.de/de/p/tru-components-1585631-tc-hp06w2f4700t5e203-dickschicht-widerstand-470-smd-1206-0-5-w-1-100-ppm-c-1-st-tape-cut-1585631.html
 |  | PinHeader 2*9 forJ2 |  |  | https://www.conrad.de/de/search.html?search=Stiftleiste%202%20*%209
 |  | ServoCable |  |  | https://www.conrad.de/de/p/econ-connect-kl3x014rtswgn25-litze-3-x-0-14-mm-rot-schwarz-gruen-25-m-2861407.html
 |  | JST XH 1*3 header for 2s Lipo |  |  | https://www.conrad.de/de/p/jst-stiftleiste-standard-xh-polzahl-gesamt-3-rastermass-2-50-mm-800184-1-st-741181.html
 |  |  |  |  | https://www.conrad.de/de/p/weller-t0051402999-loetzinn-bleifrei-sn0-6cu0-05ni-21-g-0-30-mm-0-50-mm-0-80-mm-2489829.html

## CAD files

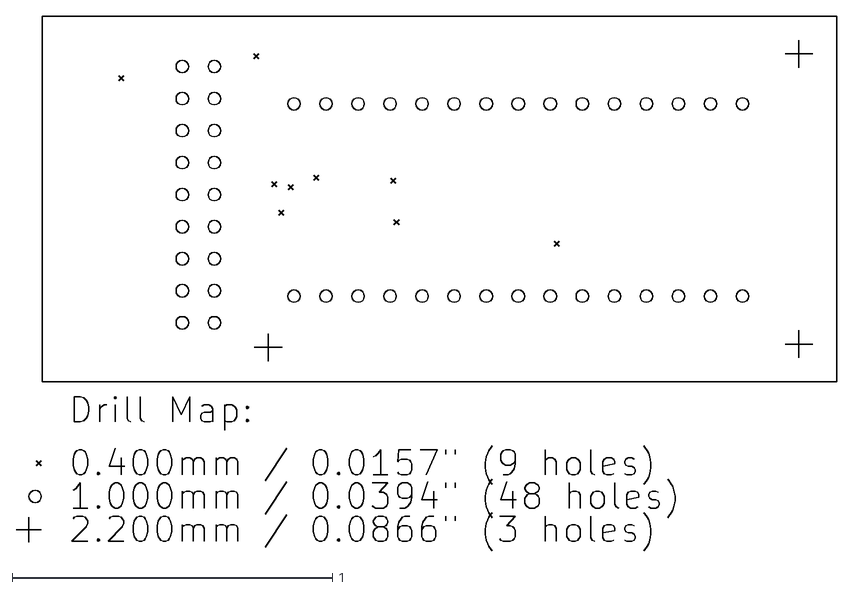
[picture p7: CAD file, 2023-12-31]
Hardware/ControlLineApp/ControlLineApp-PTH-drl_map.dxf
2.56 x 1.67

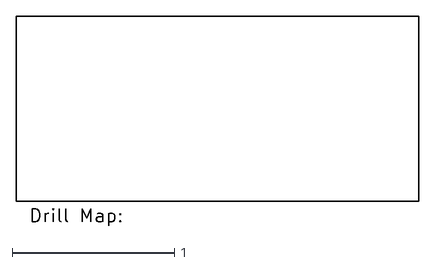
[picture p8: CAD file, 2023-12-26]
Hardware/ControlLineApp/ControlLineApp-NPTH-drl_map.dxf
2.48 x 1.29

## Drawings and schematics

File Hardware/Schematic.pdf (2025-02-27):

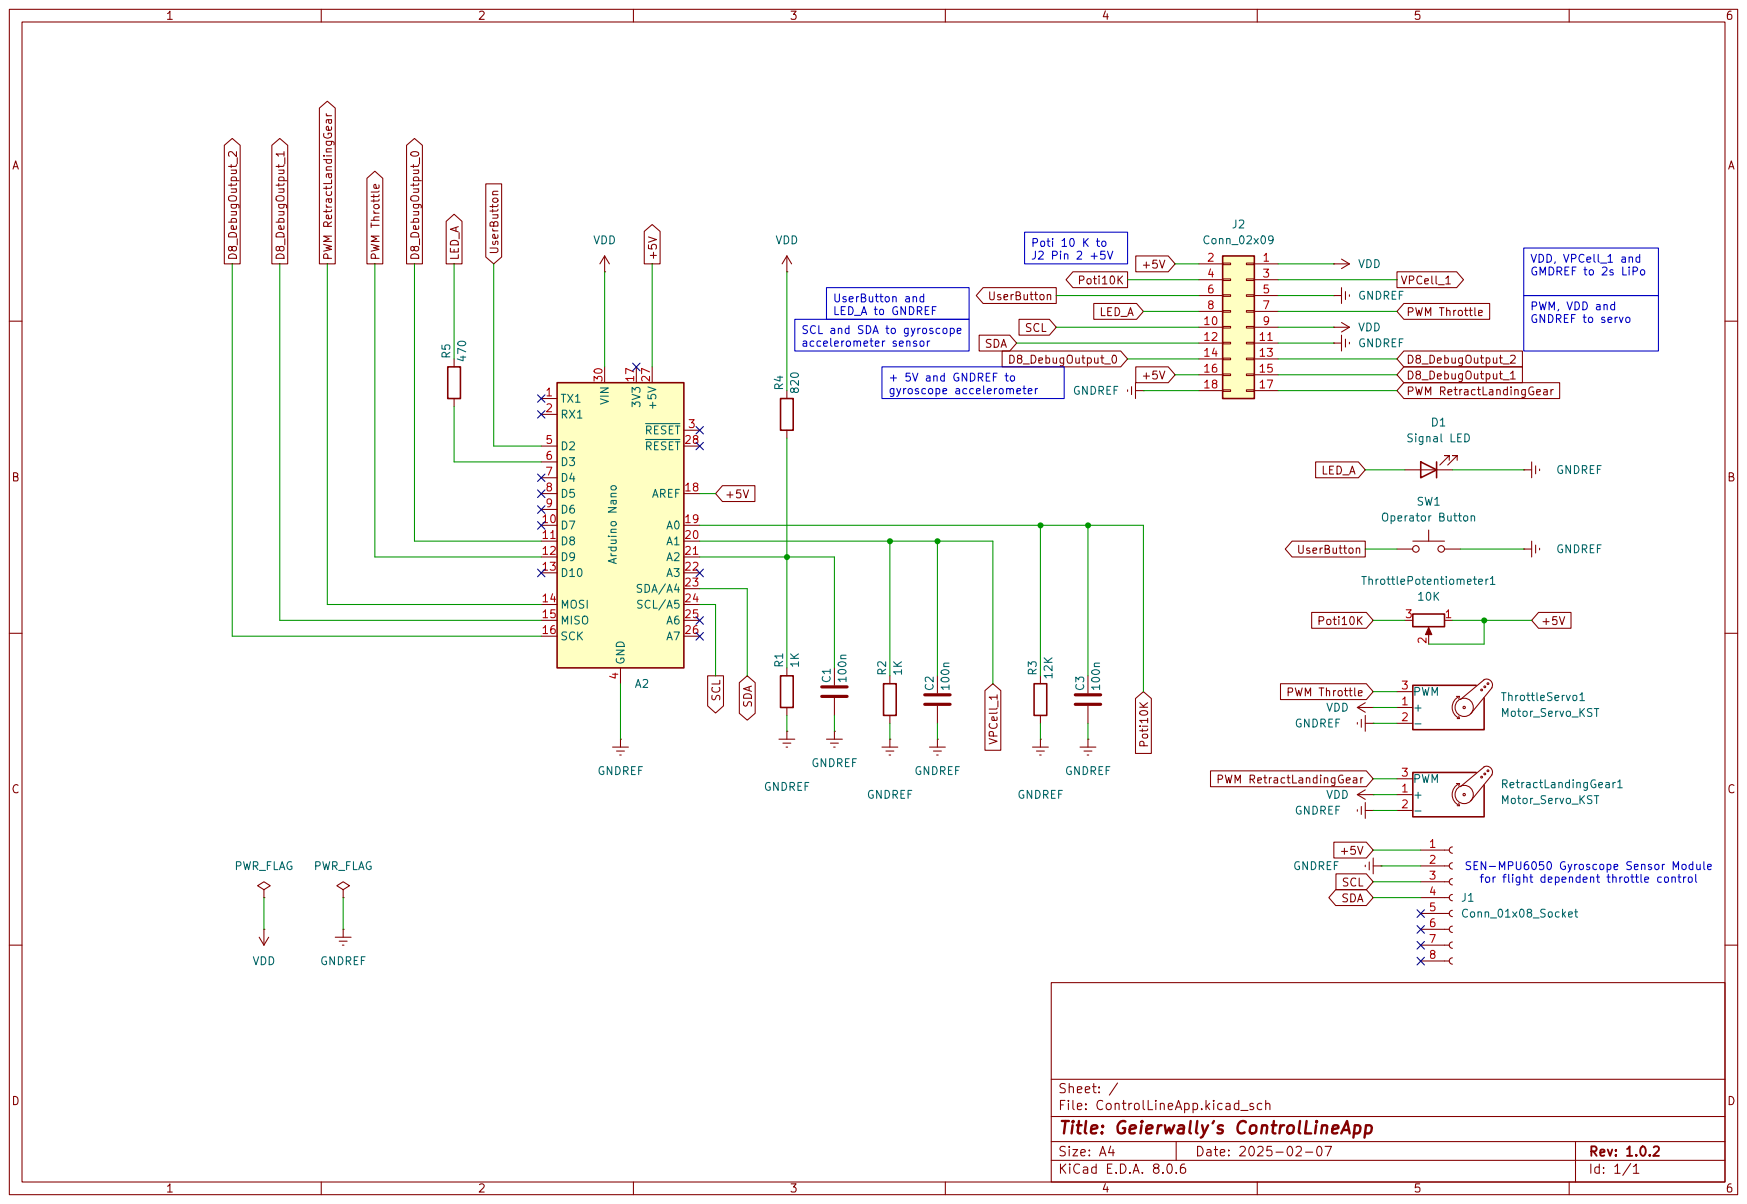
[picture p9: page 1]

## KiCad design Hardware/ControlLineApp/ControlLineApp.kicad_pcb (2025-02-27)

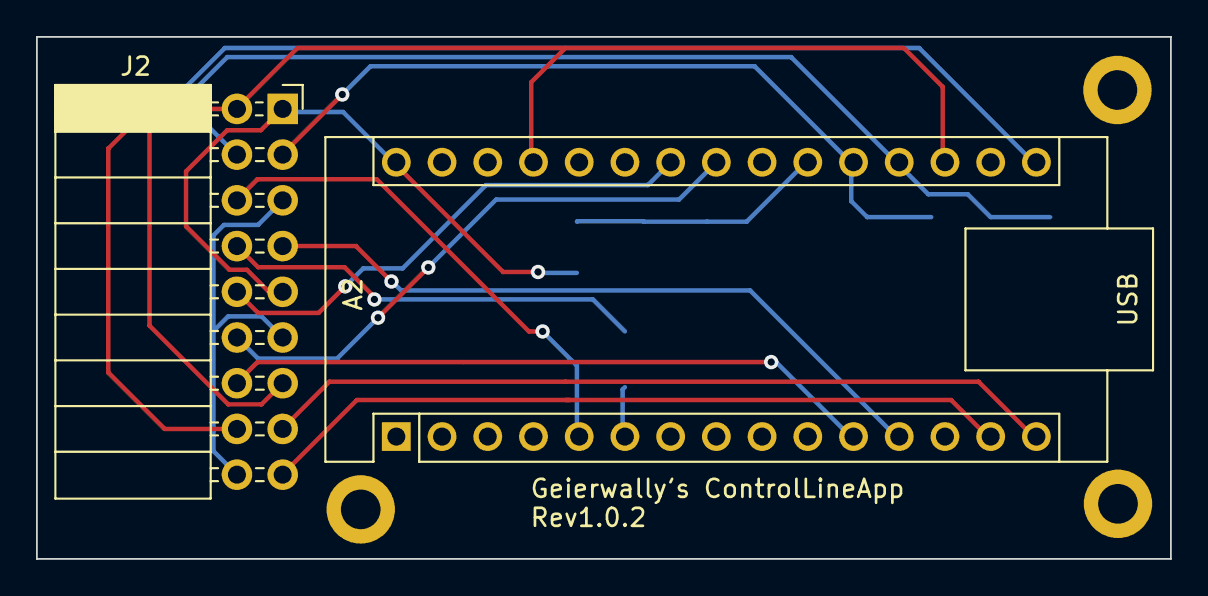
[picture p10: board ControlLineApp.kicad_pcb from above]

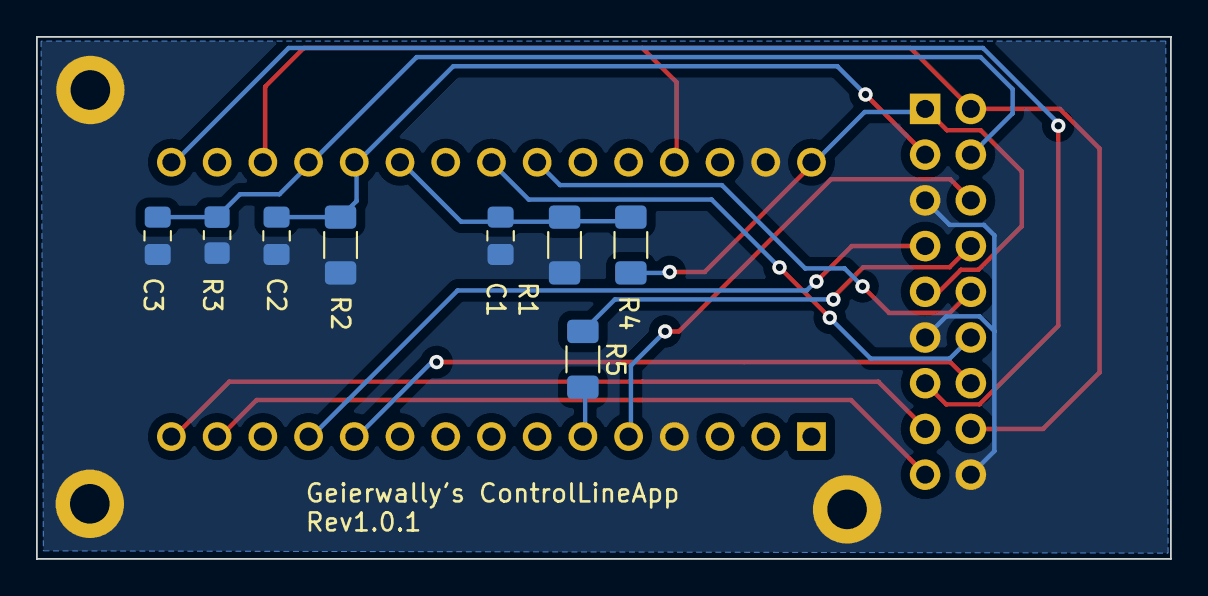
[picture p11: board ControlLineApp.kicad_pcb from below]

Board: 2 copper layers, 63.0 x 29.0 mm, 13 parts (8 on the bottom side), 16 nets.

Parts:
A2: Arduino Nano; Arduino_Nano
C1, C2, C3: 100n; C_0805_2012Metric_Pad1.18x1.45mm_HandSolder
H1, H2, H3: MountingHole_Pad; MountingHole_2.2mm_M2_DIN965_Pad
J2: Conn_02x09; PinSocket_2x09_P2.54mm_Horizontal
R1, R2: 1K; R_1206_3216Metric_Pad1.30x1.75mm_HandSolder
R3: 12K; R_0805_2012Metric_Pad1.20x1.40mm_HandSolder
R4: 820; R_1206_3216Metric_Pad1.30x1.75mm_HandSolder
R5: 470; R_1206_3216Metric_Pad1.30x1.75mm_HandSolder

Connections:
+5V: A2.18 (AREF), A2.27 (+5V), J2.2, J2.16
D8_FunctionPin3: A2.11 (D8), J2.14
D12_FunctionPin4: A2.15 (MISO), J2.15
D13_FunctionPin5: A2.16 (SCK), J2.13
GNDREF: A2.4 (GND), A2.29 (GND), C1.2, C2.2, C3.2, H1.1, H2.1, H3.1, J2.5, J2.11, J2.18, R1.1, R2.1, R3.1
LED_A: J2.8, R5.1
unnamed: A2.21 (A2), C1.1, R1.2, R4.2
unnamed: A2.6 (D3), R5.2
PWM RetractLandingGear: A2.14 (MOSI), J2.17
PWM Throttle: A2.12 (D9), J2.7
Poti10K: A2.19 (A0), C3.1, J2.4, R3.2
SCL: A2.24 (SCL/A5), J2.10
SDA: A2.23 (SDA/A4), J2.12
UserButton: A2.5 (D2), J2.6
VDD: A2.30 (VIN), J2.1, J2.9, R4.1
VPCell_1: A2.20 (A1), C2.1, J2.3, R2.2

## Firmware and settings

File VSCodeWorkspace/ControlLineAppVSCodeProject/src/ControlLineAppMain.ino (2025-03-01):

/*
 	 Name:           ControlLineAppMain.ino
 	 Description:    Geierwally's throttle, additional functions and timer application for line controlled model planes
   Version:        V1.0.1
   CycleTime:      measured on toggle output and over timer function 6ms
 	 Copyright:      Geierwally, 2025(c)
 */
#include "VoltageProtection.h"
#include "ServoControl.h"
#include "ServoFunction.h"
#include "ButtonControl.h"
#include "LedControl.h"
#include "FlightTimer.h"
#include "GyroAccelSens.h"

LedControl    statusLed_(3);                             /* status LED object for switching output LED */
ButtonControl userButton_(2, &statusLed_);               /* button object for input button connected at pin 2*/
FlightTimer   userFlightTimer(&statusLed_);              /* flight timer object for countdown flight time */
VoltageProtection voltageProtection_(A1,A2, &statusLed_);/* voltage protection object for controlling battery voltage of two cells */
GyroAccelSens gyroAccelSens_(0x68, &statusLed_);         /* gyroscope accelerometer object for measuring flight angle */
ServoControl  throttleServo_(A0,9, &statusLed_,&gyroAccelSens_); /* servo object analog input A0, pwm output pin9 */
ServoFunction retractServo_(11, &statusLed_, &throttleServo_);   /* servo object for retract landing gear pwm output pin11 */
uint8_t servoTeachActive_ = 0;                            /* value is != 0 if servo position teach is active, otherwise 0 */
uint8_t gyroTeachActive_ = 0;                             /* value is != 0 if gyroscope teach is active, otherwise 0 */
uint8_t servoFunctionTeachActive_ = 0;                    /* value is != 0 if servo function teach is active, otherwise 0 */

#ifdef MEASURE_CYCLE_TIME
int cycleTimePin = 8;                                    /* toggle pin for measuring cycle time */
int cycleTimePinState = LOW;                             /* pin state for measuring cycle time */
#endif

/*********************************************************************
 * Function: void setup(void)
 *
 * Overview: initialize all objects
 ********************************************************************/ 
void setup()
{
  Serial.begin(115200);       /* initialize the serial console print */
  throttleServo_.Setup();     /* initialize the throttle servo */
  retractServo_.Setup();      /* initialize the retractable landing gear servo */
  userButton_.Setup();        /* initialize the user button */
  statusLed_.Setup();         /* initialize the status LED */
  userFlightTimer.Setup();    /* initialize flight timer */
  voltageProtection_.Setup(); /* initialize voltage protection instance */
  gyroAccelSens_.Setup();     /* initialize gyroscope accelerometer instance */
  analogReference(DEFAULT);
  Serial.println("control line application initialized");
#ifdef MEASURE_CYCLE_TIME
  cycleTimePinState = LOW;
  digitalWrite(cycleTimePin,cycleTimePinState);
#endif  
}

/*********************************************************************
 * Function: void loop(void)
 *
 * Overview: the main loop of control line plane application
 ********************************************************************/ 
void loop() 
{
  static bool prevFlightTimeElapsed = false;
  static bool flightTimeElapsed = false;
  #ifdef MEASURE_CYCLE_TIME
  static uint32_t cycleTimeMax = 0;
  uint32_t cycleTime = 0;
  TimerMs cycleTimer;
  #endif
 
  uint8_t buttonPressState = userButton_.GetPressState();
  userButton_.Control();                                      /* read the user button */
  statusLed_.Control();                                       /* switch status LED */
  servoTeachActive_ = throttleServo_.Control(buttonPressState, servoFunctionTeachActive_);/* control the throttle servo */
  voltageProtection_.Control(buttonPressState);               /* check battery voltage */
  gyroTeachActive_  = gyroAccelSens_.Control(buttonPressState);/* measure flight angle and send to throttle control */
  servoFunctionTeachActive_ = retractServo_.Control(buttonPressState); /* control the retractable landing gear servo */
  switch(gyroTeachActive_)
  {
    case (GyroAccelSens::GyroAccel_Teach + GyroAccelSens::gt_storeFlightPosHorizontal):
      throttleServo_.StoreGyroFlightPosHorizontal();
    break;
    case (GyroAccelSens::GyroAccel_Teach + GyroAccelSens::gt_storeFlightPosThrottle):
      throttleServo_.StoreGyroFlightThrottle();
    break;
    default:
    break;
  }
  flightTimeElapsed = userFlightTimer.Control(buttonPressState,gyroTeachActive_|servoTeachActive_|servoFunctionTeachActive_);/* execute flight timer task */
  if((flightTimeElapsed == true)&&(prevFlightTimeElapsed == false))
  {
    throttleServo_.SignalThrottleEndFlight(); /* signal throttle end of flight reached */
  }
  prevFlightTimeElapsed = flightTimeElapsed;
#ifdef MEASURE_CYCLE_TIME
  cycleTimePinState = (cycleTimePinState == LOW)? HIGH : LOW; /* toggle output pin for measuring cycle time */
  digitalWrite(cycleTimePin,cycleTimePinState);
  cycleTime = cycleTimer.GetRelativeTickCount();
  if(cycleTime > cycleTimeMax)
  {
    cycleTimeMax = cycleTime;
    Serial.println("cycle time max = " + String(cycleTimeMax));
  }
  cycleTimer.Start();
#endif  
}

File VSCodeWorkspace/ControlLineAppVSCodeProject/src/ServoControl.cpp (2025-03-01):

/*
 	 Name:           ServoControl.cpp
 	 Description:    definition of controlling servo motors object
 	 Copyright:      Geierwally, 2025(c)
 */
#include "ServoControl.h"
#include "ServoFunction.h"

/*********************************************************************
 * Method: ServoControl(int controlPin, int servoPin, uint32_t moveDelay, LedControl * statusLed)
 *
 * Overview: constructor with parameters:
 * controlPin: the analog input pin for input encoder
 * servoPin:   the digital output pwm pin for servo control
 * statusLed: reference to the status led object
 * gyroAccelSens: reference to gyro accelerator sensor object
 ********************************************************************/
    ServoControl::ServoControl(int controlPin, int servoPin, LedControl * statusLed, GyroAccelSens* gyroAccelSens)
    {
      controlPin_ = controlPin;
      servoThrottlePin_ = servoPin;
      servoDelay_ = 0;
      statusLed_ = statusLed;
      gyroAccelSens_ = gyroAccelSens;
      servoCtrlState_ = Servo_Main;
      servoReverse_ = false;         /* if true servo reverse, otherwise normal */
      servoLineShortThrottle_ = false; /* no throttle on control line short active as default */
      servoLimit_ = 10;              /* maximum throttle position */
      servoThrottle_ = 20;          /* servo throttle position */
      servoGyroHorizontal_ = 10;    /* servo horizontal position for gyro flight */
      servoGyroThrottle_ = 20;      /* servo throttle position for gyro flight */
      moveVal_ = 90;                /* servo move position */
      servoCalibMinVal_ = 538;      /* servo potentiometer minimum ADC calib value */
      servoCalibMaxVal_ = 1023;      /* servo potentiometer maximum ADC calib value */
      calibrationState_ = calibrateMinVal; /* set start value for calibration task */
      functionControlState_ = functionIdle;
      functionControlThrottlePos_ = false;
    }

/*********************************************************************
 * Method: void Setup(void)
 *
 * Overview: initialize the servo control attributes
 ********************************************************************/	
    void ServoControl::Setup() 
    {
      servo_Throttle_.attach(servoThrottlePin_);    /* attaches the servo on pin 9 to the servo object */
      servoTimer_.Start();
      servoTeachTimer_.Start();
      servoEndFlightTimer_.Start();
      functionControlTimer_.Start();
      servoCtrlState_ = Servo_Main;
      servoDelay_ = gyroAccelSens_->getGyroServoSensitivity();
      moveVal_ = 90;                /* servo move position */
      servoCalibMinVal_ = eePromStorage_.readCalMinVal();
      servoCalibMaxVal_ = eePromStorage_.readCalMaxVal();
      servoThrottle_    = eePromStorage_.readServoThrottle();
      servoGyroHorizontal_ = eePromStorage_.readGyroHorizontal();
      servoGyroThrottle_ = eePromStorage_.readGyroThrottle();
      servoLimit_       = eePromStorage_.readServoLimit();
      servoLineShortThrottle_ = false; /* set true, if full throttle at line short requested */
      servoReverse_     = eePromStorage_.readServoRevers();
      functionControlThrottlePos_ = false;
      functionControlState_ = functionIdle;
      if(servoReverse_ == true)
      {val_ = 25;} /* set servo to minimum throttle position */
      else
      {val_ = 180;} /* set servo to maximum throttle position */ 
      servo_Throttle_.write(val_);
    }

/*********************************************************************
 * Method: uint8_t servoCalibrate(uint8_t buttonPressState)
 *
 * Overview: calibration task
 * calibrates min and max positions of potentiometer -
 * @param: buttonPressState  the button press state of button control
 * @return: the servo control state  
 ********************************************************************/	
    uint8_t ServoControl::servoCalibrate(uint8_t buttonPressState)
    {
      uint8_t controlState = Servo_Calibrate;
      switch (calibrationState_)
      {
        case calibrateMinVal:  /* initialize and start calibration for minimum value */
          if(buttonPressState == Servo_Store)
          {
            calibrationState_ = calibrateMaxVal;
          }
          else
          {
            /* reads the minimum value of the potentiometer (value between 0 and 1023) */
            servoCalibMinVal_ = analogRead(controlPin_);      
            if(servoTeachTimer_.IsExpired(1300))
            {
              servoTeachTimer_.Start();
              statusLed_->FlashLed(1,200,100);
            }
          }
        break;
        case calibrateMaxVal:  /* start calibration for maximum value */
          if(buttonPressState == Servo_Store)
          {
            calibrationState_ = calibrateVerify;
          }
          else
          {
            /* reads the maximum value of the potentiometer (value between 0 and 1023) */
            servoCalibMaxVal_ = analogRead(controlPin_);      
            if(servoTeachTimer_.IsExpired(1600))
            {
              servoTeachTimer_.Start();
              statusLed_->FlashLed(2,200,100);
            }
          }
        break;
        case calibrateVerify:  /* verify minimum maximum value, exchange, if necessary */
          if(servoCalibMinVal_ > servoCalibMaxVal_)
          {
            int swabVal = servoCalibMinVal_;
            servoCalibMinVal_ = servoCalibMaxVal_;
            servoCalibMaxVal_ = swabVal;
          }
          calibrationState_ = calibrateStore;
        break;
        case calibrateStore:    /* write calibration values to EEProm */
          Serial.println("calibrate minimum = " + String(servoCalibMinVal_) + "\ncalibrate maximum = " + String(servoCalibMaxVal_));
          calibrationState_ = calibrateMinVal; /* reset sub task calibrate state */
          /* store values on EEProm */
          controlState = Servo_Store; 
          eePromStorage_.writeCalMaxVal(servoCalibMaxVal_);
          eePromStorage_.writeCalMinVal(servoCalibMinVal_);
        break;
        default:
        break;
      }
      return(controlState);
    }
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

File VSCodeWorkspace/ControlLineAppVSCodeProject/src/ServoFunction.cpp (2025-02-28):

/*
 	 Name:           ServoFunction.h
 	 Description:    definition of function servo motors object
 	 Copyright:      Geierwally, 2025(c)
 */

#include "ServoFunction.h"
#include "ButtonControl.h"


/*********************************************************************
 * Method: ServoFunction(int servoPin, LedControl * statusLed)
 *
 * Overview:  constructor with parameters:
 * @param servoPin:  the digital output pwm pin for servo function
 * @param statusLed:  reference to the status led object
 * @param throttleServo_: reference to the throttle servo object
 ********************************************************************/
    ServoFunction::ServoFunction(int servoPin, LedControl * statusLed, ServoControl *  throttleServo)
    {
        servoPin_ = servoPin;
        statusLed_ = statusLed;
        servoPosition_ = 0;
        servoEndpos_ = 0;
        servoDelay_ = 0;
        servoRevers_ = false;
        servoFunctionActive_ = 0; /* servo function off 0; servo function on 1; servo function inverse 3 */
        throttleServo_ = throttleServo;
        servoFunctionCtrlState_ = ServoFunction_Main;
        expectedFunctionServoTeachState_ = sft_Idle;
        functionServoTeachState_ = sft_Idle;
        prevServoFunctionState_ = 0;
    }
    
/*********************************************************************
 * Method: void Setup(void)
 *
 * Overview: initialize the servo function attributes
 ********************************************************************/	
    void ServoFunction::Setup() 
    {
        servo_.attach(servoPin_);      /* attaches the servo on pin to the servo object */
        servoTimer_.Start();
        teachLEDTimer_.Start();
        servoEndpos_ = eepromStore_.readServoFunction();
        servoRevers_ = (bool) eepromStore_.readServoFunctionReverse();
        servoFunctionActive_ = eepromStore_.readServoFunctionActive();
        servoDelay_ = eepromStore_.readServoFunctionSpeed();
        if(servoRevers_ == true)
            {servoPosition_ = 180;}
        else
            {servoPosition_ = 25;}
        servo_.write(servoPosition_);
        prevServoFunctionState_ = statusLed_->GetFunction2State();
        switch (servoFunctionActive_)
        {
            default:
            case 0:
            /* nothing to do */
            break;
            case 1: /* normal: switch servo function 3 off */
            statusLed_->SetFunction3PinState(0);
            break;
            case 3: /* inverse switch servo function 3 on */
            statusLed_->SetFunction3PinState(1);
            break;
        }
    }
   
 /*********************************************************************
 * Method: void Control(void)
 *
 * Overview: the function servo control task
 * - move servo to end- or limit - position depending
 * - teach function servo end position
 * - calibrate potentiometer
 * @return: 1 if servo teach function is active otherwise 0
 ********************************************************************/
    uint8_t ServoFunction::Control(uint8_t buttonPressState) 
    {
        uint8_t servoFunctionState2 = 0;
        bool moveDone = false;
        switch(servoFunctionCtrlState_)
        {
            case ServoFunction_Main:      /* main task servo control */
                if(buttonPressState == ServoFunction_TeachFunction)
                {
                    servoFunctionCtrlState_ = buttonPressState;
                }
                servoFunctionState2 = statusLed_->GetFunction2State();
                if(servoFunctionState2 != prevServoFunctionState_)
                {
                    if(servoFunctionState2 == 1)
                    {
                        servoTimer_.Start(); 
                        servoFunctionCtrlState_ = ServoFunction_EndposMove;
                    }
                    else
                    {
                        servoTimer_.Start(); 
                        servoFunctionCtrlState_ = ServoFunction_LimitMove;
                    }
                    prevServoFunctionState_ = servoFunctionState2;
                }
            break;
            case ServoFunction_EndposMove: /* move servo to treached end position */  
                moveDone = servoMove(servoEndpos_);
                if(moveDone == true)
                {
                    servoFunctionCtrlState_ = ServoFunction_Main;
                    switch (servoFunctionActive_)
                    {
                        default:
                        case 0:
                        /* nothing to do */
                        break;
                        case 1: /* normal: switch servo function 3 on */
                        statusLed_->SetFunction3PinState(1);
                        break;
                        case 2: /* inverse switch servo function 3 off */
                        statusLed_->SetFunction3PinState(0);
                        break;
                    }
                }
            break; 

            case ServoFunction_LimitMove:  /* move servo to limit position */
                if(servoRevers_ == true)
                {moveDone = servoMove(180);}
                else
                {moveDone = servoMove(25);}
                if(moveDone == true)
                {
                    servoFunctionCtrlState_ = ServoFunction_Main;
                    switch (servoFunctionActive_)
                    {
                        default:
                        case 0:
                        /* nothing to do */
                        break;
                        case 1: /* normal: switch servo function 3 off */
                        statusLed_->SetFunction3PinState(0);
                        break;
                        case 2: /* inverse switch servo function 3 on */
                        statusLed_->SetFunction3PinState(1);
                        break;
                    }
                }
            break;

            case ServoFunction_TeachFunction:   /* servo teach function position */
                if(true == servoFuctionTeach(buttonPressState))
                {
                    servoFunctionCtrlState_ = ServoFunction_Main;
                }
            break;
            default:
            break;        
        }
        return(servoFunctionCtrlState_);
    }
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

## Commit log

2023-12-26 PCB and schematic designed with KiCad 7.0
    [ControlLineApp-NPTH-drl_map.dxf, ControlLineApp-PTH-drl_map.dxf, ControlLineApp.csv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]
2023-12-31 PCB and schematic adapted with I²C interface, software implementation accelerometer gyroscope
    [ControlLineApp-B_Cu.gbr, ControlLineApp-B_Mask.gbr, ControlLineApp-B_Paste.gbr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]
2024-01-21 gyro flight feature implementation finished
    [ControlLineApp-B_Cu.gbr, ControlLineApp-B_Mask.gbr, ControlLineApp-B_Paste.gbr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]
2025-02-27 App extended with additional functions like retractable landing gear
    [ControlLineApp.kicad_pcb, ControlLineApp.kicad_sch]
2025-03-01 bugfix init endposition functiion servo
    [ControlLineAppMain.ino, ServoControl.cpp]
2025-03-02 bugfix voltage protection
